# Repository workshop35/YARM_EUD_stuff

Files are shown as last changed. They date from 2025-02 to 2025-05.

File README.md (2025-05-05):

# YetAnotherRuggedMeshtasticEUD
A huge thanks to anvlmedia. This build is based off of his initial design for a rugged Meshtastic enclosure. Our modifications externalize the LoRa and GPS antennas. Additionally, we also make use of a weather resistant USB-C adapter in place of the original Fischer connector to increase accessibility.
 
## Assembly

### Parts List
- 1x [Lid](https://github.com/justcallmekoko/YetAnotherRuggedMeshtasticEUD/blob/main/Mechanical/STLs/Lid.stl)
- 1x [Main Body](https://github.com/justcallmekoko/YetAnotherRuggedMeshtasticEUD/blob/main/Mechanical/STLs/Main%20Body.stl)
- 1x [Gasket](https://github.com/justcallmekoko/YetAnotherRuggedMeshtasticEUD/blob/main/Mechanical/STLs/Gasket.stl)
- 1x [Knob](https://github.com/justcallmekoko/YetAnotherRuggedMeshtasticEUD/blob/main/Mechanical/STLs/Knob.stl)
- 1x [56D36-01-2-AJN Rotary Switch](https://www.digikey.com/en/products/detail/grayhill-inc/56D36-01-2-AJN/98655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) or [56SDP36-01-2-AJN Rotary Switch](https://www.digikey.com/en/products/detail/grayhill-inc/56SDP36-01-2-AJN/2678565)
- 1x [USB-C Adapter](https://www.aliexpress.us/item/3256804440339698.html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)
- 1x [USB-C Adapter Cap](https://www.aliexpress.us/item/3256805936943547.html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)
- 2x [SMA Connector](https://www.digikey.com/en/products/detail/gct/cab412rf-0100-a-1-e/22251137)
- 3x [Light Pipe](https://www.digikey.com/en/products/detail/visual-communications-company-vcc/LMC-080-CTP/4515531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)
- 6x [M3 Brass Insert](https://www.mcmaster.com/94180A331/)
- 6x [M3 x 30mm Screws](https://www.mcmaster.com/91294A141/)
- 1x [RAK19007](https://store.rakwireless.com/products/rak19007-wisblock-base-board-2nd-gen)
- 1x [Wisblock GPS Module](https://store.rakwireless.com/products/wisblock-gnss-location-module-rak12500)
- 1x RAK Core Module
- 1x [2.0 JST Connector](https://www.amazon.com/dp/B07NWD5NTN?ref_=ppx_hzsearch_conn_dt_b_fed_asin_title_1)
- 1x 3.7v 504050 LiPo Battery

### Assembly of components

#### Rotary Switch
1. Install the end stop pins that came with your switch in the positions shown in the following image where one is placed between `9` and `10`, and the other is placed between `1` and `2`.
    - *Note: Before installing the pins, ensure the flat side of the rotary switch shaft is at position `5` or `6`*
      <p align="left">Switch Pins</p>

3. Solder the black wires of your male and female JST cables together
4. Solder the red wire of the male JST cable to the "6-10" center pin of the rotary switch
5. Solder the red wire of the female JST cable to the `6` pin
    - *Note: Your wiring should look like the following image*
      <p align="left">Wiring</p>

6. Install all of your bulkhead components including SMA connectors, rotary switch, and USB connector
    - *Note: The USB connector can only be installed one way*
    - *Note: The rotary switch must be installed to that postitions `5` and `6` are facting up*
      <p align="left">Bulkhead</p>

#### Main Board
1. Install the Wisblock GPS module on the RAK19007 board using the included small screw
      <p align="left">GPS</p>
      
3. Insert the USB-C plug of the USB-C adapter into your RAK19007 board
    - *Note: Route the cable so that it tucks under the SMA pigtails and rotary switch*
      <p align="left">USB Cable</p>

4. Install the main board into the main enclosure body using the RAK included screws
5. Connect the pigtail cables to their respective IPEX connectors including the BLE antenna that came with your RAK device
6. Press fit the BLE antenna in the small slot next to the main board
      <p align="left">BLE Antenna</p>

#### Enclosure
1. Install six M3 brass inserts in the back of the enclosure main body
      <p align="left">Brass</p>
      
2. Install three light pipes in the `C`, `H`, and `U` positions on your enclosure lid
      <p align="left">Light Pipes</p>

3. Using double-sided tape, attach your LiPo pack to the inside of the enclosure lid
      <p align="left">Battery</p>

4. Place the gasket and lid onto the enclosure main body so that the gasket is between the lid and main body
      <p align="left">Gasket</p>

5. Using six M3x30mm screws, fasten the enclosure shut
6. Install the power switch knob onto the rotary switch
      <p align="left">Gasket</p>

## Usage
- **The design is not intended to be waterproof.** It is simply meant to be water and dust resistant
- To power the unit on, place the switch in the `I` position
- To power the unit off, place the switch in the `O` position
- Charge and program the device through the USB-C power mounted to the enclosure bulkhead
- When connected to USB-C power, the device will only charge the battery when the switch is in the `I` position
- When connected to USB-C power, the device will power on even if the switch is in the `O` position
- Connect a GPS antenna to the SMA connector labeled `G`
- Connect a LoRa antenna to the SMA connector labeled `L`
- Use the side grid panel for indentification markings

## Extra Printed Components
- There are extra files located in the "STL" folder if you wish to print your own light pipes and USB passthrough.
  
  <a href="https://github.com/workshop35/YARM_EUD_stuff/blob/06f0664fd07bfb7e5f15abcb8ad2165e72d469b8/Mechanical/STLs/mainBodyEdit.3mf">Case</a>
  
  <a href="https://github.com/workshop35/YARM_EUD_stuff/blob/06f0664fd07bfb7e5f15abcb8ad2165e72d469b8/Mechanical/STLs/usbPassthrough.3mf">USB Passthrough</a>

  <a href="https://github.com/workshop35/YARM_EUD_stuff/blob/0d7214ca557dbc08e7389d28ac9c6c2bc0039537/Mechanical/STLs/usbNut.3mf">Nut</a>
  
  <a href="https://github.com/workshop35/YARM_EUD_stuff/blob/06f0664fd07bfb7e5f15abcb8ad2165e72d469b8/Mechanical/STLs/usbCap.3mf">Dust Cap</a>
  
  <a href="https://github.com/workshop35/YARM_EUD_stuff/blob/06f0664fd07bfb7e5f15abcb8ad2165e72d469b8/Mechanical/STLs/capLanyard.3mf">Cap Lanyard</a>

  <a href="https://github.com/workshop35/YARM_EUD_stuff/blob/0d7214ca557dbc08e7389d28ac9c6c2bc0039537/Mechanical/STLs/lightPipe.3mf">Light Pipe</a>

- Extra Purchase
  [USB-C Breakout Boards](https://a.co/d/73ktVuH)

   https://github.com/user-attachments/assets/33cab01c-ab12-4689-82cd-6a3599bcc097

- The case is modified to remove the lanyard opening, the antenna mounting flange thickness is reduced, the the USB passthrough opening was altered.
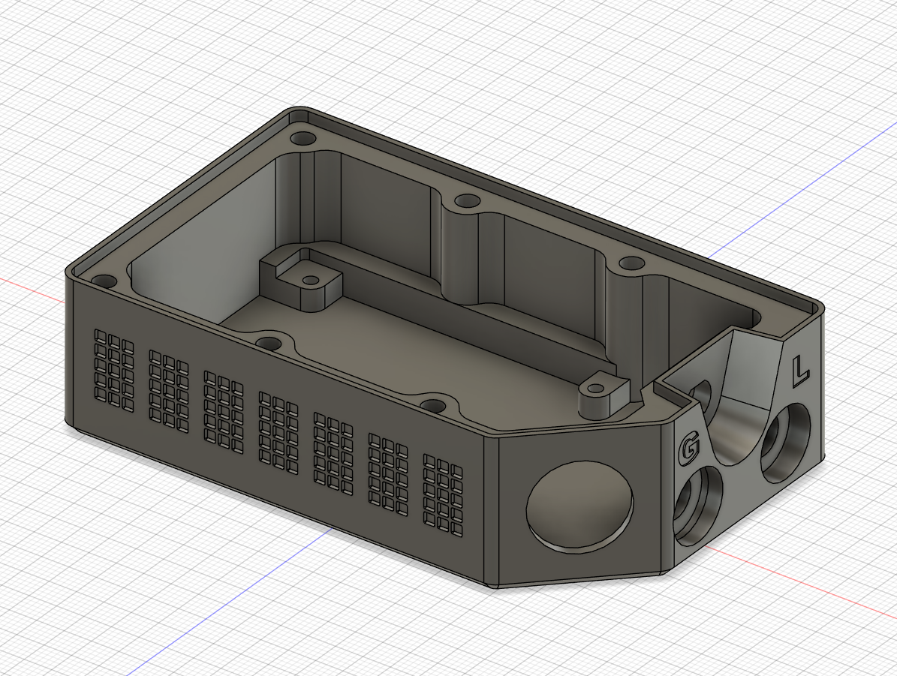
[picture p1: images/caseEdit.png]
Case
  
  
- The lightpipe is printed in clear PETG. **The "Arachne" wall generator was used in OrcaSlicer.** Insert a pipe into each opening and fix with an adhesive.
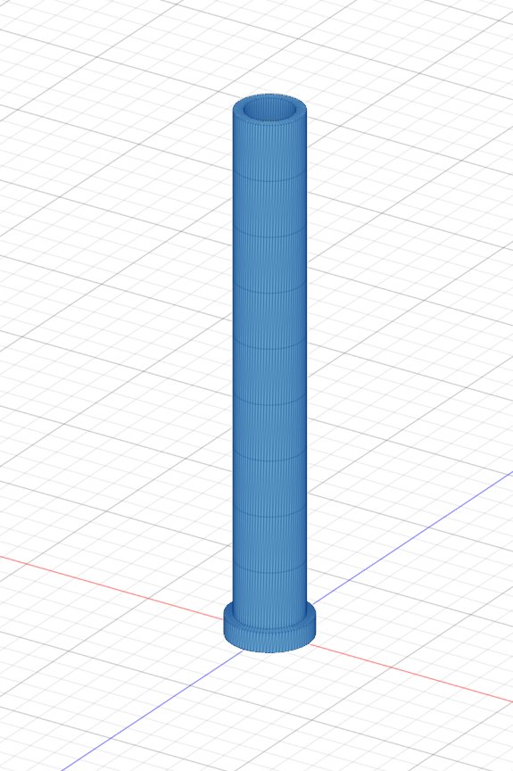
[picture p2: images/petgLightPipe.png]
Light Pipe
  

- The USB passthrough is four parts: USB-C holder, retention nut, cap, and lanyard. The lanyard was printed in TPU.
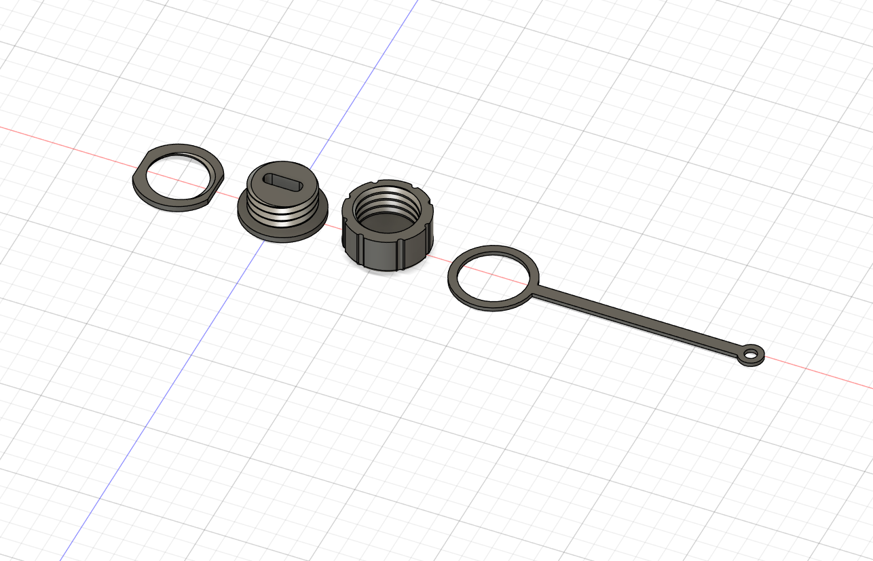
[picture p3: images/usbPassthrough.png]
Components
  

- Press-fit the female USB breakout board into the holder. This is a very tight fit and may require adjustments to the print depending on your printer.
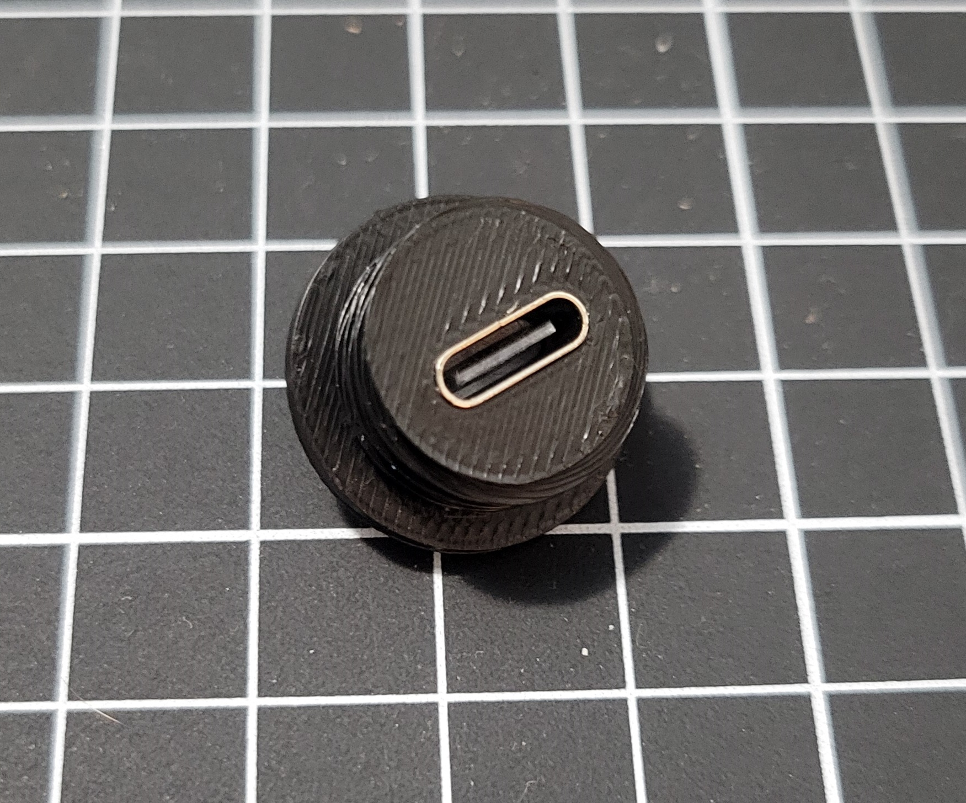
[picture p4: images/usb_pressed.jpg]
USB Pressed-In
  

- Cut roughly two inches of a four-conductor ribbon cable (four individual wires also work). Solder one end to the female USB breakout in the holder from the previous step. Solder the other to a male USB breakout. The connections are straight through without crossover. Use 3/8" or equivalent shrink tube to insulate the connections.
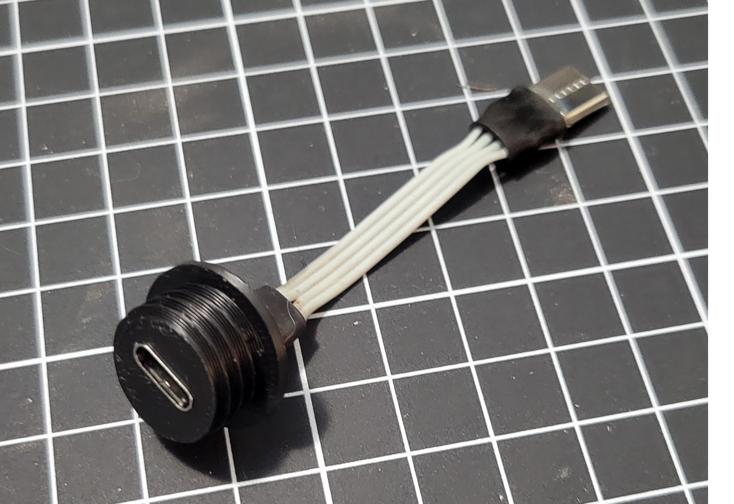
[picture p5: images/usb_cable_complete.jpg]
USB Cable
   

- Install the male end of the cable into the RAK19007 board. You may have to loosen the board for it to fit. **This will not fit into the original case, you must use the modified version linked above**.
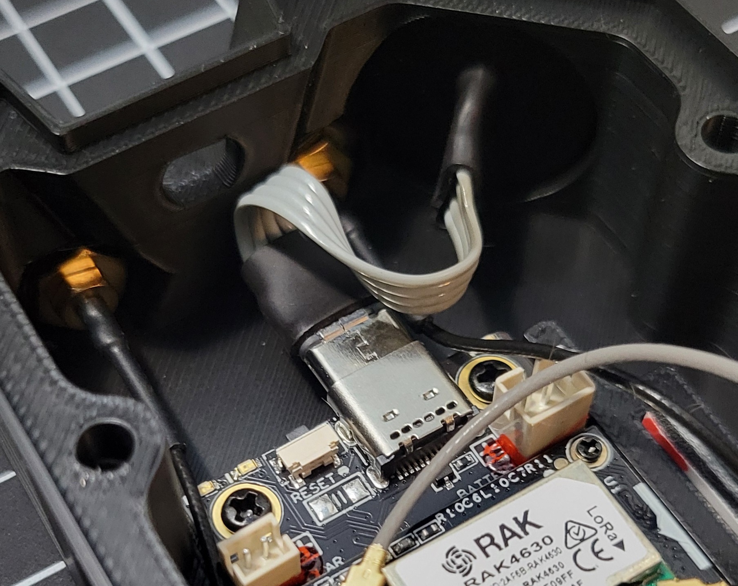
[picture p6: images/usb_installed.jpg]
Cable Install
  

- Verify functionality by connecting a USB power source.
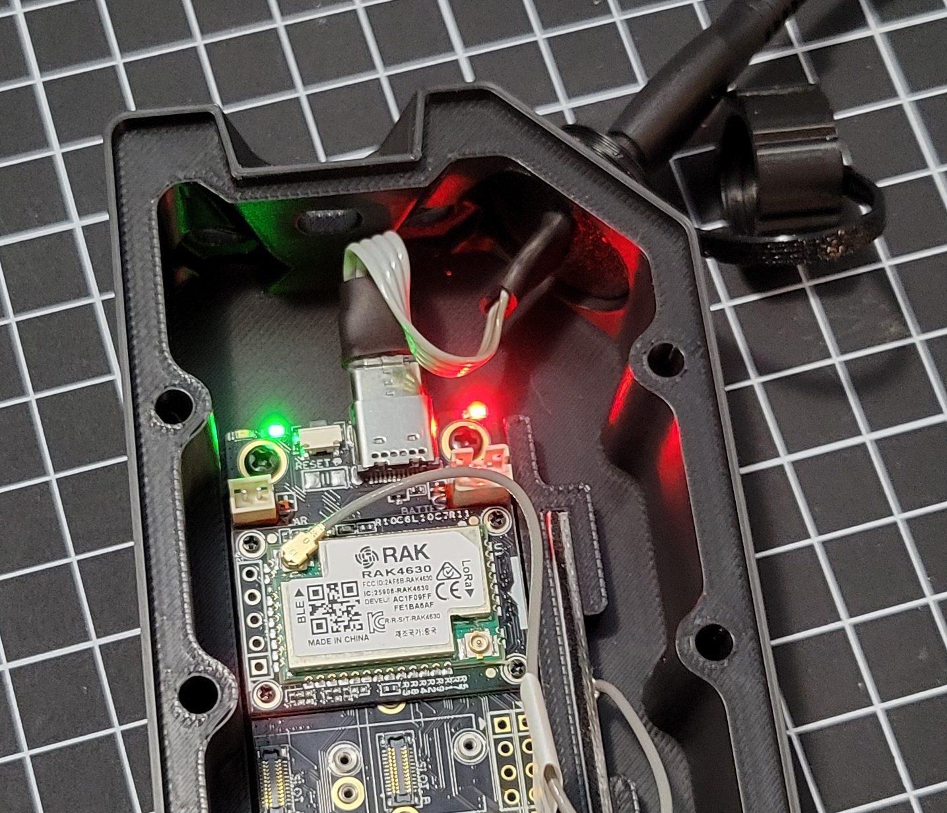
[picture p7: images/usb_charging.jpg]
Ops Check


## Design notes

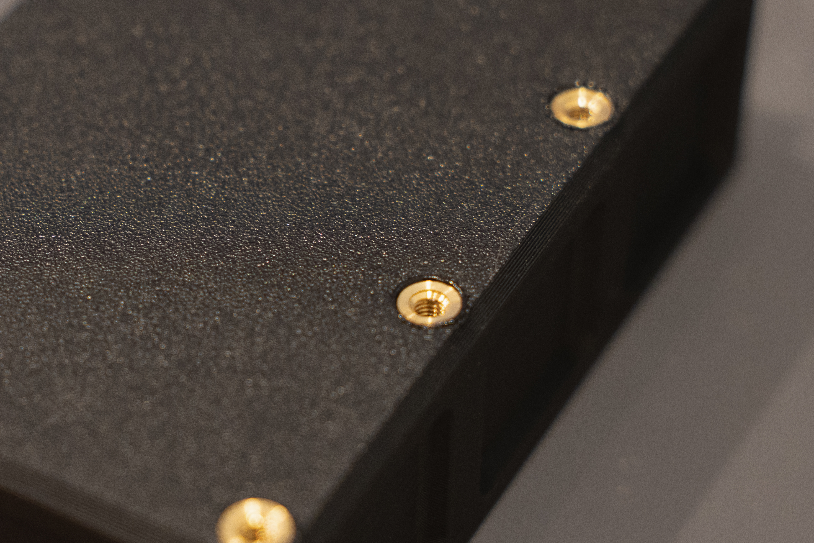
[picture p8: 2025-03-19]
images/threads.jpg

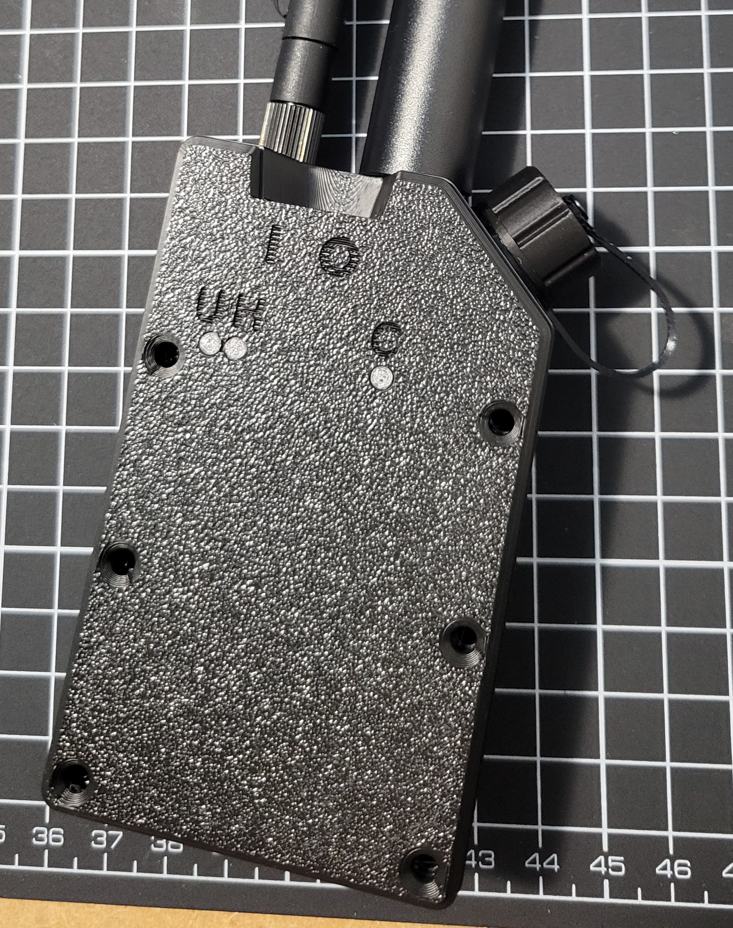
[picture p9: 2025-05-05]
images/caseWithPassthrough.jpg

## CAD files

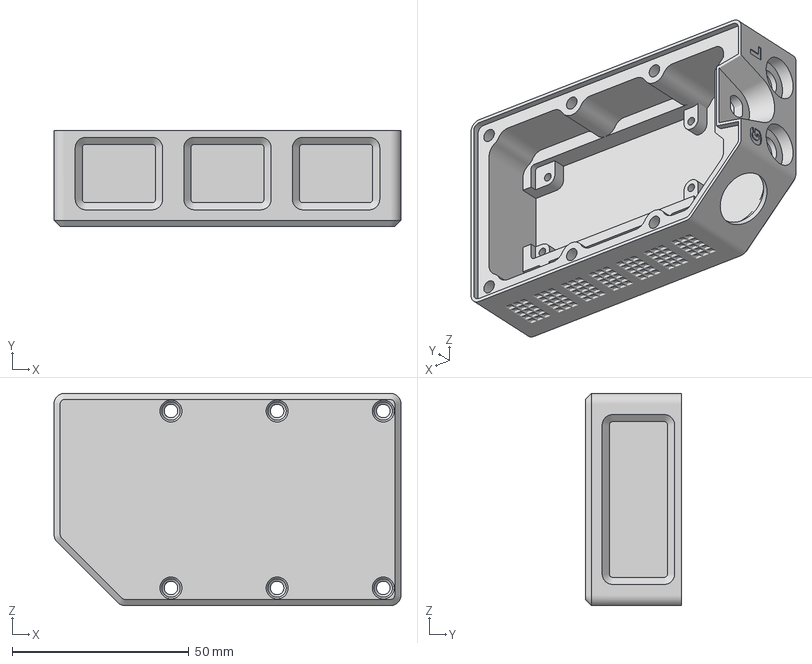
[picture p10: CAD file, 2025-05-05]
Mechanical/STLs/mainBodyEdit.3mf
98.1 x 27.2 x 60.0 mm

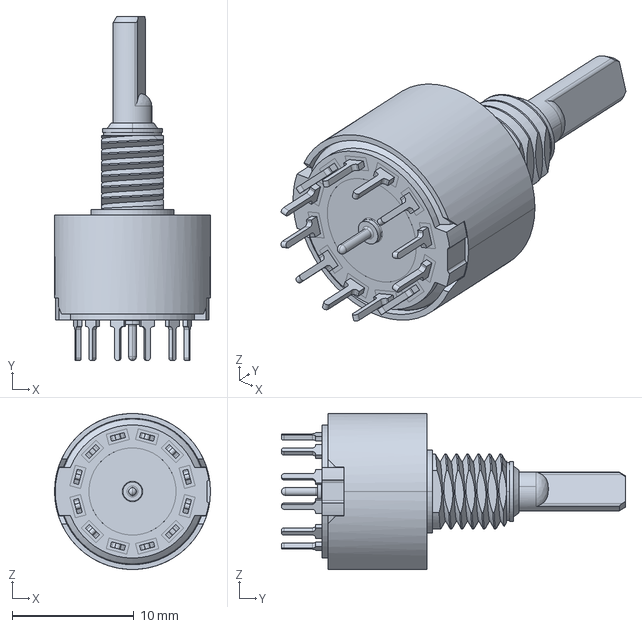
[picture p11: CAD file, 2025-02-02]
Mechanical/Parts/56dp30-01-1-ajn.stp
12.8 x 28.3 x 12.8 mm

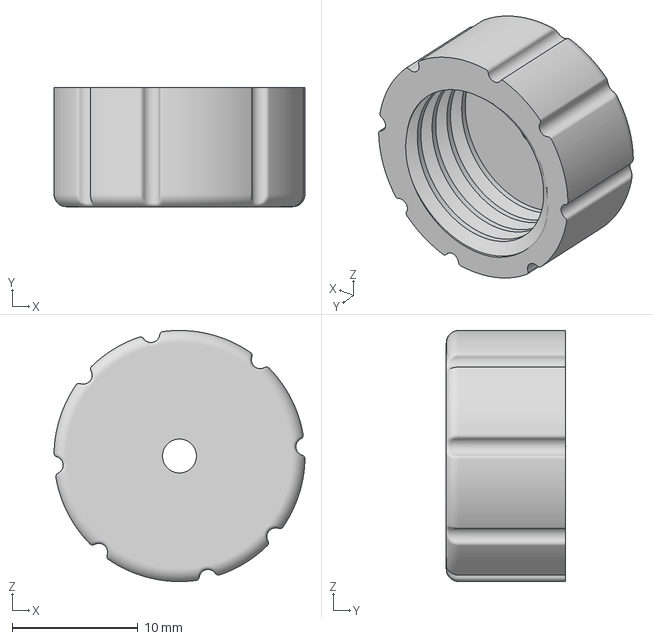
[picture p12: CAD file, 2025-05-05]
Mechanical/STLs/usbCap.3mf
20.0 x 9.52 x 20.0 mm

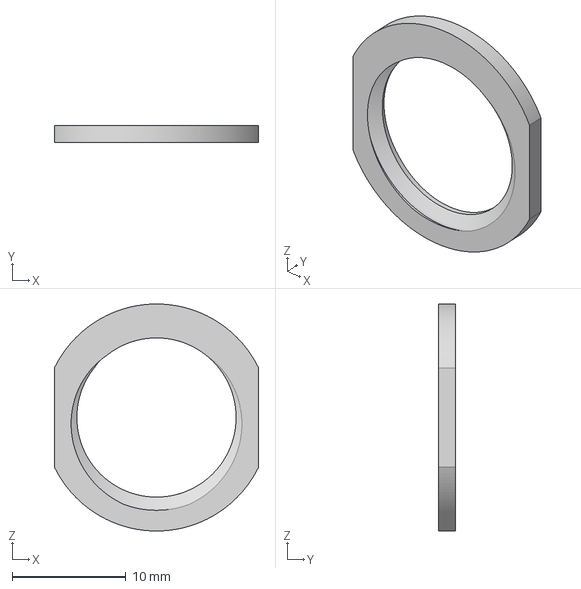
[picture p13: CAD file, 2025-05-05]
Mechanical/STLs/usbNut.3mf
18.0 x 1.50 x 20.0 mm

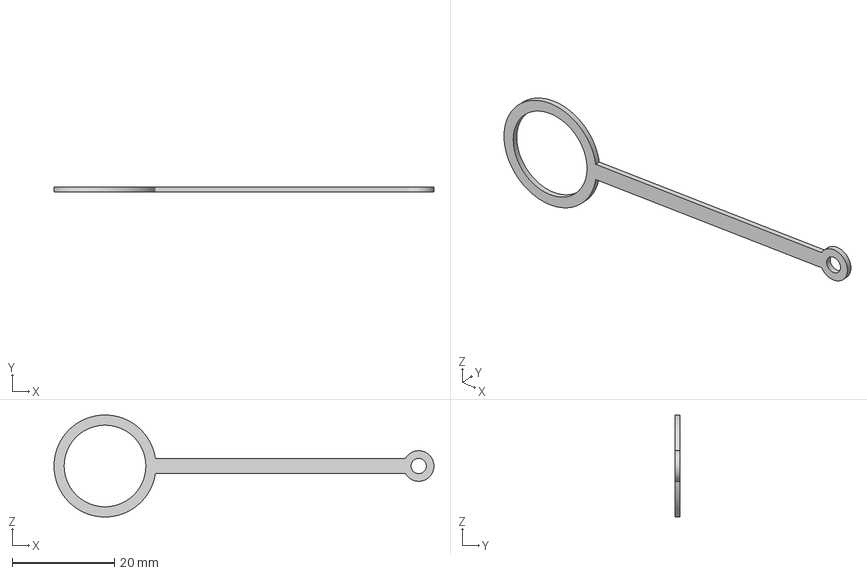
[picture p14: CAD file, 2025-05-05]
Mechanical/STLs/capLanyard.3mf
74.5 x 1.00 x 20.0 mm

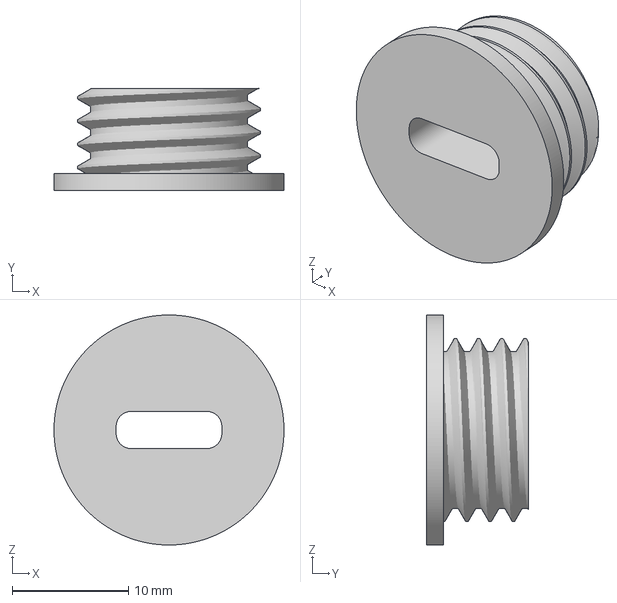
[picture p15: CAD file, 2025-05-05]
Mechanical/STLs/usbPassthrough.3mf
19.8 x 8.82 x 19.8 mm

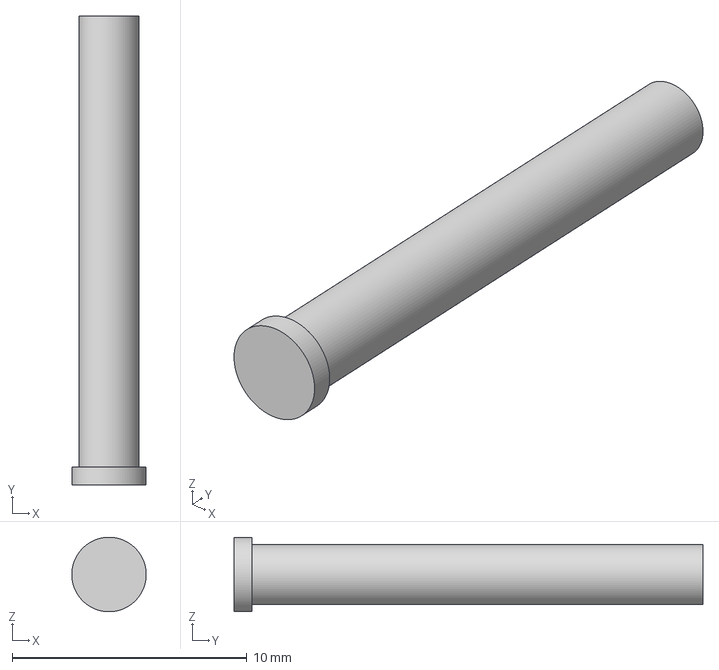
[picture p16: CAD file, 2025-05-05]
Mechanical/STLs/lightPipe.3mf
3.17 x 20.0 x 3.17 mm

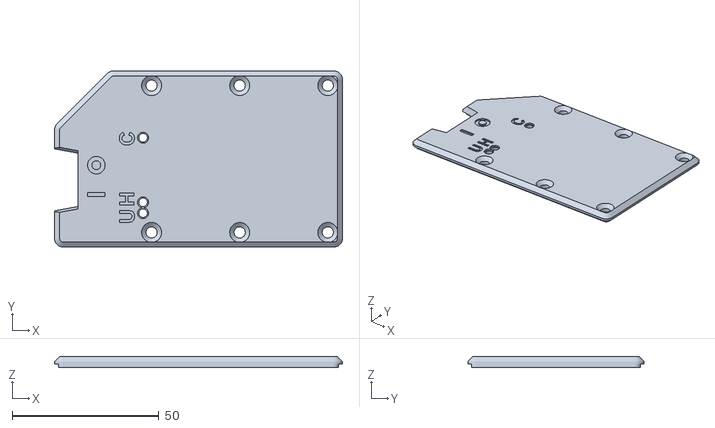
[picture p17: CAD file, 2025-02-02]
Mechanical/STLs/Lid.stl
98.1 x 60.0 x 3.80

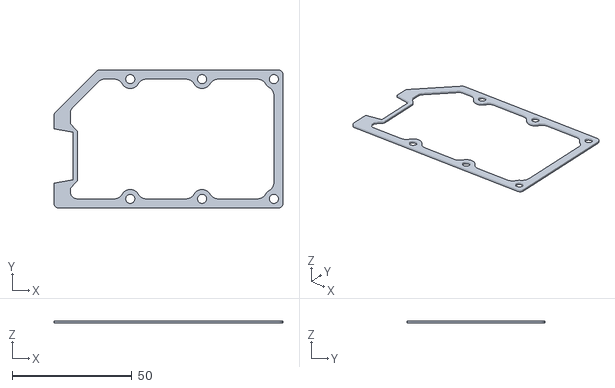
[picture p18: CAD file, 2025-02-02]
Mechanical/STLs/Gasket.stl
95.7 x 57.6 x 1.00

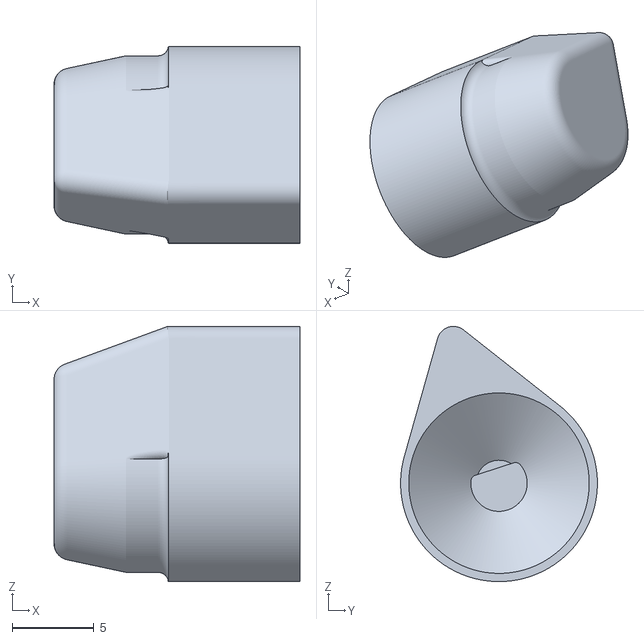
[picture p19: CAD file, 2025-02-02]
Mechanical/STLs/Knob.stl
15.0 x 12.0 x 15.6

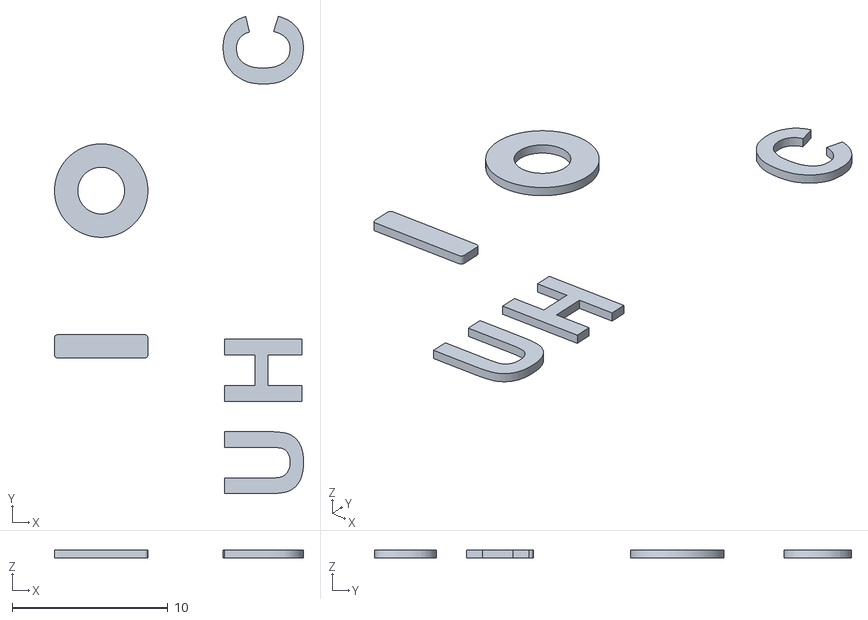
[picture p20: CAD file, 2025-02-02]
Mechanical/STLs/On_Off_Inlay.stl
16.0 x 30.7 x 0.5

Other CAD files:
Mechanical/STLs/Main Body.stl

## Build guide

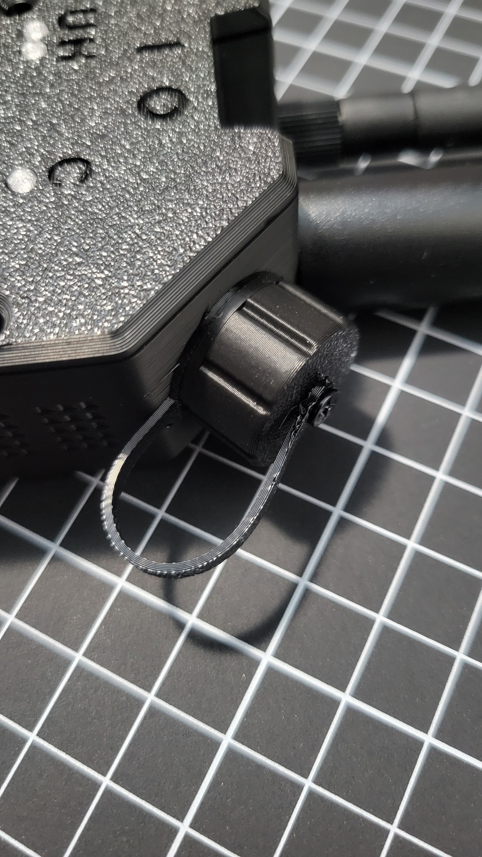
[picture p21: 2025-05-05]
images/capInstalled.jpg

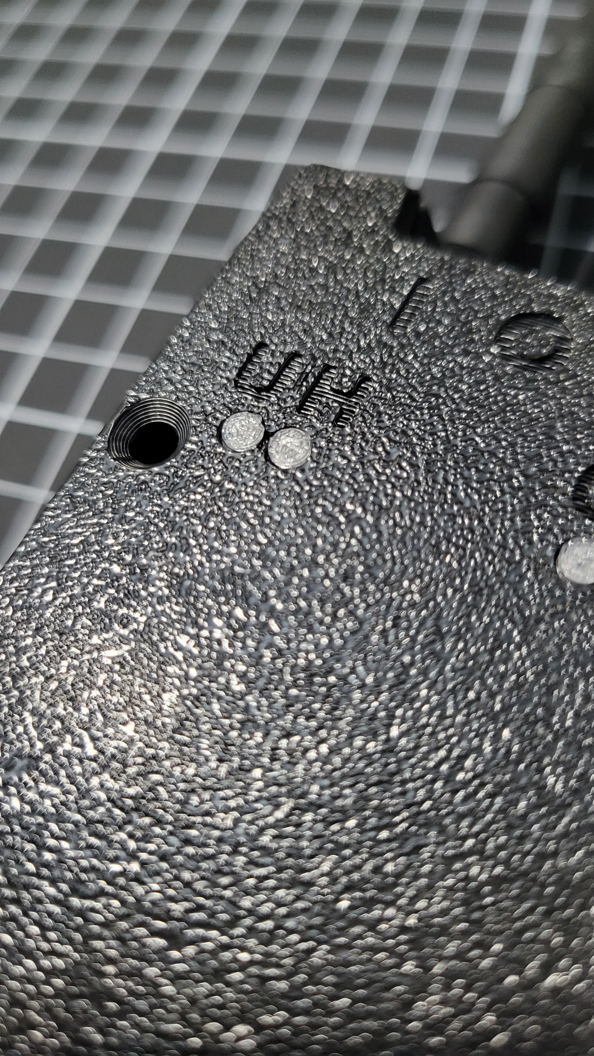
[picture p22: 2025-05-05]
images/LightpipeInstalled.jpg

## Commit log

2025-02-04 Update SMA connector link
2025-02-04 Update rotary switch list
2025-03-19 Add assembly and usage instructions
2025-04-30 Update README.md
    Added assembly pictures
